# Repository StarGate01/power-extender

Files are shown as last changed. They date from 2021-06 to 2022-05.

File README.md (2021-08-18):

# Power Extender

Hardware and software for a power and IO extension PCB with current monitoring and I2C interface.

This project has been generously supported by [PCBWay](https://www.pcbway.com/). Read more about this project and also my review of the manufacturing on my blog: [Design And Assembly Of An I2C Relay PCB](https://chrz.de/2021/07/16/design-and-assembly-of-an-i2c-relay-pcb/)

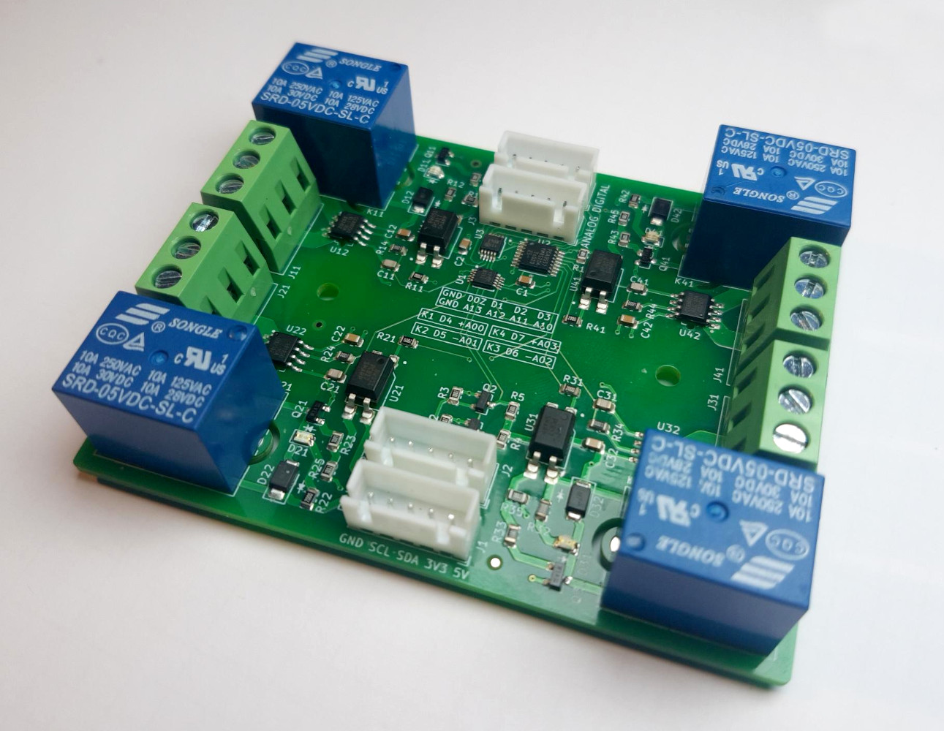
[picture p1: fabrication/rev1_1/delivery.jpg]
PCB


## Usage

Use [KiCad](https://www.kicad.org/) with my [CustomComponents](https://github.com/StarGate01/KiCadLibs) library to view and edit the hardware project, or download the [fabrication files](fabrication) for PCB and/or PCBA manufacturing. I used [KiBOM](https://github.com/SchrodingersGat/kibom) to generate the BOM. You can also download the complete [schematics as PDF](hardware/power-extender_schematics_rev1_1.pdf).

See the [Arduino library documentation](https://github.com/StarGate01/power-extender/tree/master/software/power-extender-arduino/lib/power-extender) for usage with the Arduino framework. The library is also available on [PlatformIO](https://platformio.org/lib/show/12563/power-extender). Use [Visual Studio Code](https://code.visualstudio.com/) and the [PlatformIO](https://platformio.org/) plugin to edit the Arduino library and tests.

See the [Raspberry Pi library documentation](https://github.com/StarGate01/power-extender/tree/master/software/power-extender-raspberrypi) for usage with the Raspberry Pi Python 3 `smbus` framework.

## Features and Specifications

- Power input via `5V` and `3V3` pins
  - Min. `250mA @ 5V` to actuate all four relays simultaneously
  - Less than `30mA @ 5V` standby current
  - `3V3` voltage level is only required for I2C level shifting if the I2C signal level is `3.3V` instead of `5V`
- I2C bus for connection to a I2C master via JST header `RPI`
  - I2C bus passthrough via JST header `PASS`
  - Internal pullup resistors
  - Level-shifting `3.3V - 5V` tolerant bus
- Four `SRD-05VDC-SL-C` three-lead (`NC - COM - NO`) magnetic relays
  - Each has a `CC6902SO-10A` inductive current measuring IC connected across `COM`
  - Galvanically isolated driver circuit using an optocoupler
  - Flyback diode protection
  - Red status LED indicates `COM - NO` actuation
  - `2oz` thick copper traces enable high currents
  - Isolation milling reduces risk of shorting in damp environments
  - Maximum power: `10A, 250VAC, 110VDC`
  - Contact load rating: resistive `7A @ 28VDC`, `10A @ 125VAC`, `7A @ 240VAC`, inductive `3A @ 120VAC`, `3A @ 28VDC`
- One `PCA9557` 8-channel GPIO port (I2C address: `0x18`), logic level `0V | 5V`
  - GPIO channels `0Z` - `3` connected to JST header `DIGITAL`
  - Relays are connected to GPIO channels `4` - `7`
  - Maximum current (except channel `0Z`): `25mA` sink, `20mA` source per channel, max. total: `100mA` sink, `85mA` source
  - Channel `0Z` is high-impedance and open-drain (see datasheet for details)
- Two `ADS1115` 4-channel 16-bit ADC ports, voltage range `0V - 5V`
  - All four pins of ADC 1 connected to current measuring ICs (I2C address: `0x48`)
  - All four pins of ADC 2 connected to JST header `ANALOG` (I2C address: `0x49`)
  - Configurable sample rate and gain amplifier
  - Max. `10mA` continuous input current

For further specifications and ratings, all [datasheets](https://github.com/StarGate01/power-extender/tree/master/datasheets) can be found in this repository.

### Sensor Calibration

Due to the inherent nature of magnetic relays, the inductive current measuring ICs and also the ADCs experience a measurement offset while the relays are energized. It is recommended to measure the actual load at a distance from the board, in order to obtain reference values. These reference values should then be used to compute an offset or function for each channel and amount of relays energized. 

For no load (floating) using an Arduino Uno, the maximum absolute measurement offset was found to be about as follows.

| Amount of relays energized | Offset at energized channel | Offset at disabled channel |
| --- | --- | --- |
| 0 | `0.05A` | `0.05A` |
| 1 | `1A` | `0.7A` |
| 2 | `1.5A` | `1.3A` |
| 3 | `2A` | `1.8A` |
| 4 | `2.4A` | N / A |

Please note that these offsets are dependent on load and environmental factors.

## PCB Details

**17 unique** parts, **60 SMT** parts, **12 THT** parts on a double-sided `90mm x 71mm` PCB with `2oz` copper finish.

Component cost per board: about `$25` (Ignoring shipping, bulk discounts and changes in price over time).

<details>
<summary>BOM</summary>

|Item #|Designator |Quantity|Manufacturer |Manufacturer Part #  |Description / Value |Distributor|Distributor part #|Package / Footprint|Type|Notes|
|---|---|---|---|---|---|---|---|---|----|-----|
|1 |C11, C21, C31, C41 |4 |Any |TBD |CAP CER 100PF MAX. 5% MIN. 10V 0805 SMD |Any |TBD |SMD 0805 |SMD | |
|2 |C1, C2, C12, C22, C32, C42 |6 |Any |TBD |CAP CER 100NF MAX. 5% MIN. 10V 0805 SMD |Any |TBD |SMD 0805 |SMD | |
|3 |D12, D22, D32, D42 |4 |Shikues |1N4007F |DIODE 1N4007 SMAF |LCSC |C110856 |SMAF |SMD | |
|4 |D11, D21, D31, D41 |4 |Everlight Elec |17-21SURC/S530-A3/TR8|LED RED 2V 0805 SMD |LCSC |C72037 |SMD 0805 |SMD | |
|5 |J1, J2, J3, J4 |4 |Any |TBD |CONN JST-XH PITCH-2.50MM VERTICAL MALE 5 PIN|Any |TBD |Through Hole |PTH | |
|6 |J11, J21, J31, J41 |4 |Ningbo Kangnex Elec |WJ128V-5.0-3P |CONN SCREW TERMINAL PITCH-5.0MM 3 PIN 20A |LCSC |C8270 |Through Hole |PTH | |
|7 |K11, K21, K31, K41 |4 |Ningbo Songle Relay |SRD-05VDC-SL-C |RELAY SEALED SENSITIVE 5V 10A |LCSC |C35449 |Through Hole |PTH | |
|8 |Q1, Q2 |2 |Shikues |BSS138 |MOSFET N-CH SOT-23-3 |LCSC |C112239 |SOT-23-3 |SMD | |
|9 |Q11, Q21, Q31, Q41 |4 |Nexperia |PMBT3904,215 |BJT NPN SOT-23-3 |LCSC |C8667 |SOT-23-3 |SMD | |
|10 |R14, R24, R34, R44 |4 |Any |TBD |RES 100 OHM MAX. 1% MIN. 1/8W 0805 SMD |Any |TBD |SMD 0805 |SMD | |
|11 |R11, R12, R21, R22, R31, R32, R41, R42|8 |Any |TBD |RES 200 OHM MAX. 1% MIN. 1/8W 0805 SMD |Any |TBD |SMD 0805 |SMD | |
|12 |R1, R13, R23, R33, R43 |5 |Any |TBD |RES 1K OHM MAX. 1% MIN. 1/8W 0805 SMD |Any |TBD |SMD 0805 |SMD | |
|13 |R2, R3, R4, R5, R15, R25, R35, R45 |8 |Any |TBD |RES 10K OHM MAX. 1% MIN. 1/8W 0805 SMD |Any |TBD |SMD 0805 |SMD | |
|14 |U1, U3 |2 |Texas Instruments |ADS1115IDGSR |IC I2C 4 CH ADC VSSOP-10 |LCSC |C37593 |VSSOP-10 |SMD | |
|15 |U12, U22, U32, U42 |4 |Cross Chip |CC6902SO-10A |IC CURRENT SENSOR 5V 10A SOP-8 |LCSC |C350865 |SOP-8 |SMD | |
|16 |U11, U21, U31, U41 |4 |Sharp Microelectronics|PC817X2CSP9F |IC OPTOCOUPLER SMD-4 |LCSC |C66405 |SMD-4 |SMD | |
|17 |U2 |1 |NXP Semicon |PCA9557PW,118 |IC I2C 8 CH IO EXPANDER TSSOP-16 |LCSC |C141380 |TSSOP-16 |SMD | |

</details>

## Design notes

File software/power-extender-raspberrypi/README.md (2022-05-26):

# namespace `power-extender-raspberrypi::pypowerextender::ADS1115_Registers` 

## Summary

 Members                        | Descriptions                                
--------------------------------|---------------------------------------------
`class `[`power-extender-raspberrypi::pypowerextender::ADS1115_Registers::ADS1115_DR`](#classpower-extender-raspberrypi_1_1pypowerextender_1_1ADS1115__Registers_1_1ADS1115__DR) | 
`class `[`power-extender-raspberrypi::pypowerextender::ADS1115_Registers::ADS1115_PGA`](#classpower-extender-raspberrypi_1_1pypowerextender_1_1ADS1115__Registers_1_1ADS1115__PGA) | 

# class `power-extender-raspberrypi::pypowerextender::ADS1115_Registers::ADS1115_DR` 

```
class power-extender-raspberrypi::pypowerextender::ADS1115_Registers::ADS1115_DR
  : public IntEnum
```  

## Summary

 Members                        | Descriptions                                
--------------------------------|---------------------------------------------

## Members

# class `power-extender-raspberrypi::pypowerextender::ADS1115_Registers::ADS1115_PGA` 

```
class power-extender-raspberrypi::pypowerextender::ADS1115_Registers::ADS1115_PGA
  : public IntEnum
```  

## Summary

 Members                        | Descriptions                                
--------------------------------|---------------------------------------------

## Members

# namespace `power-extender-raspberrypi::pypowerextender::PowerExtender` 

## Summary

 Members                        | Descriptions                                
--------------------------------|---------------------------------------------
`class `[`power-extender-raspberrypi::pypowerextender::PowerExtender::PEPIN_A`](#classpower-extender-raspberrypi_1_1pypowerextender_1_1PowerExtender_1_1PEPIN__A) | Existing analog pins.
`class `[`power-extender-raspberrypi::pypowerextender::PowerExtender::PEPIN_D_IN`](#classpower-extender-raspberrypi_1_1pypowerextender_1_1PowerExtender_1_1PEPIN__D__IN) | Existing GPIO pins for input.
`class `[`power-extender-raspberrypi::pypowerextender::PowerExtender::PEPIN_D_OUT`](#classpower-extender-raspberrypi_1_1pypowerextender_1_1PowerExtender_1_1PEPIN__D__OUT) | Existing GPIO pins for output.
`class `[`power-extender-raspberrypi::pypowerextender::PowerExtender::PEPORT_A`](#classpower-extender-raspberrypi_1_1pypowerextender_1_1PowerExtender_1_1PEPORT__A) | Existing analog ports (separate ADC ICs)
`class `[`power-extender-raspberrypi::pypowerextender::PowerExtender::PINMODE`](#classpower-extender-raspberrypi_1_1pypowerextender_1_1PowerExtender_1_1PINMODE) | Pinmode definitions.
`class `[`power-extender-raspberrypi::pypowerextender::PowerExtender::PINSTATE`](#classpower-extender-raspberrypi_1_1pypowerextender_1_1PowerExtender_1_1PINSTATE) | Pinstate definitions.
`class `[`power-extender-raspberrypi::pypowerextender::PowerExtender::PowerExtender`](#classpower-extender-raspberrypi_1_1pypowerextender_1_1PowerExtender_1_1PowerExtender) | Class to interface the power-extender.

# class `power-extender-raspberrypi::pypowerextender::PowerExtender::PEPIN_A` 

```
class power-extender-raspberrypi::pypowerextender::PowerExtender::PEPIN_A
  : public IntEnum
```  

Existing analog pins.

## Summary

 Members                        | Descriptions                                
--------------------------------|---------------------------------------------

## Members

# class `power-extender-raspberrypi::pypowerextender::PowerExtender::PEPIN_D_IN` 

```
class power-extender-raspberrypi::pypowerextender::PowerExtender::PEPIN_D_IN
  : public IntEnum
```  

Existing GPIO pins for input.

## Summary

 Members                        | Descriptions                                
--------------------------------|---------------------------------------------

## Members

# class `power-extender-raspberrypi::pypowerextender::PowerExtender::PEPIN_D_OUT` 

```
class power-extender-raspberrypi::pypowerextender::PowerExtender::PEPIN_D_OUT
  : public IntEnum
```  

Existing GPIO pins for output.

## Summary

 Members                        | Descriptions                                
--------------------------------|---------------------------------------------

## Members

# class `power-extender-raspberrypi::pypowerextender::PowerExtender::PEPORT_A` 

```
class power-extender-raspberrypi::pypowerextender::PowerExtender::PEPORT_A
  : public IntEnum
```  

Existing analog ports (separate ADC ICs)

## Summary

 Members                        | Descriptions                                
--------------------------------|---------------------------------------------

## Members

# class `power-extender-raspberrypi::pypowerextender::PowerExtender::PINMODE` 

```
class power-extender-raspberrypi::pypowerextender::PowerExtender::PINMODE
  : public IntEnum
```  

Pinmode definitions.

## Summary

 Members                        | Descriptions                                
--------------------------------|---------------------------------------------

## Members

# class `power-extender-raspberrypi::pypowerextender::PowerExtender::PINSTATE` 

```
class power-extender-raspberrypi::pypowerextender::PowerExtender::PINSTATE
  : public IntEnum
```  

Pinstate definitions.

## Summary

 Members                        | Descriptions                                
--------------------------------|---------------------------------------------

## Members

# class `power-extender-raspberrypi::pypowerextender::PowerExtender::PowerExtender` 

Class to interface the power-extender.

## Summary

 Members                        | Descriptions                                
--------------------------------|---------------------------------------------
`public def `[`__init__`](#classpower-extender-raspberrypi_1_1pypowerextender_1_1PowerExtender_1_1PowerExtender_1ad7f74c05e4f81fff44294663b4eea909)`(self)` | Construct a new Power Extender object.
`public def `[`begin`](#classpower-extender-raspberrypi_1_1pypowerextender_1_1PowerExtender_1_1PowerExtender_1a77635c29b3e975602f4de08570c5ab66)`(self,int bus)` | Begin I2C communication.
`public def `[`setPinMode`](#classpower-extender-raspberrypi_1_1pypowerextender_1_1PowerExtender_1_1PowerExtender_1a28935d2fa3f4e8e0b9178cc93a20c7da)`(self,`[`PEPIN_D_IN`](#classpower-extender-raspberrypi_1_1pypowerextender_1_1PowerExtender_1_1PEPIN__D__IN)` pin,`[`PINMODE`](#classpower-extender-raspberrypi_1_1pypowerextender_1_1PowerExtender_1_1PINMODE)` mode)` | Configure the IO direction of a GPIO pin.
`public def `[`digitalWrite`](#classpower-extender-raspberrypi_1_1pypowerextender_1_1PowerExtender_1_1PowerExtender_1ab420235d8b39cf3ac0c35061d8b65c75)`(self,`[`PEPIN_D_OUT`](#classpower-extender-raspberrypi_1_1pypowerextender_1_1PowerExtender_1_1PEPIN__D__OUT)` pin,`[`PINSTATE`](#classpower-extender-raspberrypi_1_1pypowerextender_1_1PowerExtender_1_1PINSTATE)` val)` | Change the state of a GPIO output pin.
`public `[`PINSTATE`](#classpower-extender-raspberrypi_1_1pypowerextender_1_1PowerExtender_1_1PINSTATE)` `[`digitalRead`](#classpower-extender-raspberrypi_1_1pypowerextender_1_1PowerExtender_1_1PowerExtender_1a331cdf53cb1d2a52321073b417b7b7f9)`(self,`[`PEPIN_D_IN`](#classpower-extender-raspberrypi_1_1pypowerextender_1_1PowerExtender_1_1PEPIN__D__IN)` pin)` | Reads the state of a digital input pin.
`public def `[`setAnalogDataRate`](#classpower-extender-raspberrypi_1_1pypowerextender_1_1PowerExtender_1_1PowerExtender_1afaa7bde6af7c3c3387ab650a0db28946)`(self,`[`PEPORT_A`](#classpower-extender-raspberrypi_1_1pypowerextender_1_1PowerExtender_1_1PEPORT__A)` port,`[`ADS1115_Registers.ADS1115_DR`](#classpower-extender-raspberrypi_1_1pypowerextender_1_1ADS1115__Registers_1_1ADS1115__DR)` data_rate)` | Set the data rate for a whole ADC.
`public def `[`setAnalogGain`](#classpower-extender-raspberrypi_1_1pypowerextender_1_1PowerExtender_1_1PowerExtender_1aebfcff18640a7b7a253666d899e245f7)`(self,`[`PEPORT_A`](#classpower-extender-raspberrypi_1_1pypowerextender_1_1PowerExtender_1_1PEPORT__A)` port,`[`ADS1115_Registers.ADS1115_PGA`](#classpower-extender-raspberrypi_1_1pypowerextender_1_1ADS1115__Registers_1_1ADS1115__PGA)` gain)` | Set the gain for a whole ADC.
`public float `[`analogReadAsVoltage`](#classpower-extender-raspberrypi_1_1pypowerextender_1_1PowerExtender_1_1PowerExtender_1a7926271bf71a0f24b47373fe16b307e5)`(self,`[`PEPIN_A`](#classpower-extender-raspberrypi_1_1pypowerextender_1_1PowerExtender_1_1PEPIN__A)` pin)` | Reads from an ADC, convert to input voltage.
`public float `[`analogReadAsCurrent`](#classpower-extender-raspberrypi_1_1pypowerextender_1_1PowerExtender_1_1PowerExtender_1a526f8b8f57397ae1fa46358c1610d534)`(self,`[`PEPIN_A`](#classpower-extender-raspberrypi_1_1pypowerextender_1_1PowerExtender_1_1PEPIN__A)` pin)` | Reads from an ADC, convert to output from current sensor.

## Members

#### `public def `[`__init__`](#classpower-extender-raspberrypi_1_1pypowerextender_1_1PowerExtender_1_1PowerExtender_1ad7f74c05e4f81fff44294663b4eea909)`(self)` 

Construct a new Power Extender object.

#### `public def `[`begin`](#classpower-extender-raspberrypi_1_1pypowerextender_1_1PowerExtender_1_1PowerExtender_1a77635c29b3e975602f4de08570c5ab66)`(self,int bus)` 

Begin I2C communication.

#### `public def `[`setPinMode`](#classpower-extender-raspberrypi_1_1pypowerextender_1_1PowerExtender_1_1PowerExtender_1a28935d2fa3f4e8e0b9178cc93a20c7da)`(self,`[`PEPIN_D_IN`](#classpower-extender-raspberrypi_1_1pypowerextender_1_1PowerExtender_1_1PEPIN__D__IN)` pin,`[`PINMODE`](#classpower-extender-raspberrypi_1_1pypowerextender_1_1PowerExtender_1_1PINMODE)` mode)` 

Configure the IO direction of a GPIO pin.

#### Parameters
* `pin` Which pin to configure 

* `mode` INPUT or OUTPUT

#### `public def `[`digitalWrite`](#classpower-extender-raspberrypi_1_1pypowerextender_1_1PowerExtender_1_1PowerExtender_1ab420235d8b39cf3ac0c35061d8b65c75)`(self,`[`PEPIN_D_OUT`](#classpower-extender-raspberrypi_1_1pypowerextender_1_1PowerExtender_1_1PEPIN__D__OUT)` pin,`[`PINSTATE`](#classpower-extender-raspberrypi_1_1pypowerextender_1_1PowerExtender_1_1PINSTATE)` val)` 

Change the state of a GPIO output pin.

#### Parameters
* `pin` Which pin to change 

* `val` HIGH or LOW

#### `public `[`PINSTATE`](#classpower-extender-raspberrypi_1_1pypowerextender_1_1PowerExtender_1_1PINSTATE)` `[`digitalRead`](#classpower-extender-raspberrypi_1_1pypowerextender_1_1PowerExtender_1_1PowerExtender_1a331cdf53cb1d2a52321073b417b7b7f9)`(self,`[`PEPIN_D_IN`](#classpower-extender-raspberrypi_1_1pypowerextender_1_1PowerExtender_1_1PEPIN__D__IN)` pin)` 

Reads the state of a digital input pin.

#### Parameters
* `pin` Which pin to read 

#### Returns
HIGH or LOW

#### `public def `[`setAnalogDataRate`](#classpower-extender-raspberrypi_1_1pypowerextender_1_1PowerExtender_1_1PowerExtender_1afaa7bde6af7c3c3387ab650a0db28946)`(self,`[`PEPORT_A`](#classpower-extender-raspberrypi_1_1pypowerextender_1_1PowerExtender_1_1PEPORT__A)` port,`[`ADS1115_Registers.ADS1115_DR`](#classpower-extender-raspberrypi_1_1pypowerextender_1_1ADS1115__Registers_1_1ADS1115__DR)` data_rate)` 

Set the data rate for a whole ADC.

#### Parameters
* `port` Which ADC port to configure 

* `data_rate` The new data rate

#### `public def `[`setAnalogGain`](#classpower-extender-raspberrypi_1_1pypowerextender_1_1PowerExtender_1_1PowerExtender_1aebfcff18640a7b7a253666d899e245f7)`(self,`[`PEPORT_A`](#classpower-extender-raspberrypi_1_1pypowerextender_1_1PowerExtender_1_1PEPORT__A)` port,`[`ADS1115_Registers.ADS1115_PGA`](#classpower-extender-raspberrypi_1_1pypowerextender_1_1ADS1115__Registers_1_1ADS1115__PGA)` gain)` 

Set the gain for a whole ADC.

#### Parameters
* `port` Which ADC to configure 

* `gain` The new gain

#### `public float `[`analogReadAsVoltage`](#classpower-extender-raspberrypi_1_1pypowerextender_1_1PowerExtender_1_1PowerExtender_1a7926271bf71a0f24b47373fe16b307e5)`(self,`[`PEPIN_A`](#classpower-extender-raspberrypi_1_1pypowerextender_1_1PowerExtender_1_1PEPIN__A)` pin)` 

Reads from an ADC, convert to input voltage.

#### Parameters
* `pin` Which pin to read 

#### Returns
The resulting value in volt

#### `public float `[`analogReadAsCurrent`](#classpower-extender-raspberrypi_1_1pypowerextender_1_1PowerExtender_1_1PowerExtender_1a526f8b8f57397ae1fa46358c1610d534)`(self,`[`PEPIN_A`](#classpower-extender-raspberrypi_1_1pypowerextender_1_1PowerExtender_1_1PEPIN__A)` pin)` 

Reads from an ADC, convert to output from current sensor.

#### Parameters
* `pin` Which pin to read 

#### Returns
The resulting value in ampere

Generated by [Moxygen](https://sourcey.com/moxygen)

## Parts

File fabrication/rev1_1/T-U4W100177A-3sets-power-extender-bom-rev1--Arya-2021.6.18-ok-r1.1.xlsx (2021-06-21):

Item # | Designator | Quantity | Manufacturer | Manufacturer Part # | Description / Value | Distributor | Distributor part # | Package / Footprint | Type | Notes | Unit price 3sets |  | NOTE
1 | C11, C21, C31, C41 | 4 | Any | TBD | CAP CER 100PF MAX. 5% MIN. 10V 0805 SMD | Any | TBD | SMD 0805 | SMD | OK | $0.055 | $0.660 | CL21C101JBANNNC(CAP CER 100PF 50V C0G/NP0 0805),ok？
2 | C1, C2, C12, C22, C32, C42 | 6 | Any | TBD | CAP CER 100NF MAX. 5% MIN. 10V 0805 SMD | Any | TBD | SMD 0805 | SMD | OK | $0.105 | $1.890 | CC0805JRX7R9BB104(CAP CER 0.1UF 50V X7R 0805),ok？
3 | D12, D22, D32, D42 | 4 | Shikues | 1N4007F | DIODE 1N4007 SMAF | LCSC | C110856 | SMAF | SMD |  | $0.055 | $0.660
4 | D11, D21, D31, D41 | 4 | Everlight Elec | 17-21SURC/S530-A3/TR8 | LED RED 2V 0805 SMD | LCSC | C72037 | SMD 0805 | SMD |  | $0.105 | $1.260
5 | J1, J2, J3, J4 | 4 | Any | TBD | CONN JST-XH PITCH-2.50MM VERTICAL MALE 5 PIN | Any | TBD | Through Hole | PTH | OK, Must use PCB Rev 1.1 | $0.210 | $2.520 | XH2.54mm 5p male socket, 180 degree in vertical,ok?
6 | J11, J21, J31, J41 | 4 | Ningbo Kangnex Elec | WJ128V-5.0-3P | CONN SCREW TERMINAL PITCH-5.0MM 3 PIN 20A | LCSC | C8270 | Through Hole | PTH |  | $0.195 | $2.340
7 | K11, K21, K31, K41 | 4 | Ningbo Songle Relay | SRD-05VDC-SL-C | RELAY SEALED SENSITIVE 5V 10A | LCSC | C35449 | Through Hole | PTH |  | $0.398 | $4.776
8 | Q1, Q2 | 2 | Shikues | BSS138 | MOSFET N-CH SOT-23-3 | LCSC | C112239 | SOT-23-3 | SMD |  | $0.125 | $0.750
9 | Q11, Q21, Q31, Q41 | 4 | Nexperia | PMBT3904,215 | BJT NPN SOT-23-3 | LCSC | C8667 | SOT-23-3 | SMD |  | $0.325 | $3.900
10 | R14, R24, R34, R44 | 4 | Any | TBD | RES 100 OHM MAX. 1% MIN. 1/8W 0805 SMD | Any | TBD | SMD 0805 | SMD | OK | $0.055 | $0.660 | RC0805FR-07100RL(RES SMD 100 OHM 1% 1/8W 0805),ok？
11 | R11, R12, R21, R22, R31, R32, R41, R42 | 8 | Any | TBD | RES 200 OHM MAX. 1% MIN. 1/8W 0805 SMD | Any | TBD | SMD 0805 | SMD | OK | $0.055 | $1.320 | RC0805FR-07200RL(RES SMD 200 OHM 1% 1/8W 0805),ok？
12 | R1, R13, R23, R33, R43 | 5 | Any | TBD | RES 1K OHM MAX. 1% MIN. 1/8W 0805 SMD | Any | TBD | SMD 0805 | SMD | OK | $0.055 | $0.825 | RC0805FR-071KL(RES SMD 1K OHM 1% 1/8W 0805),ok？
13 | R2, R3, R4, R5, R15, R25, R35, R45 | 8 | Any | TBD | RES 10K OHM MAX. 1% MIN. 1/8W 0805 SMD | Any | TBD | SMD 0805 | SMD | OK | $0.055 | $1.320 | RC0805FR-0710KL(RES SMD 10K OHM 1% 1/8W 0805),ok？
14 | U1, U3 | 2 | Texas Instruments | ADS1115IDGSR | IC I2C 4 CH ADC VSSOP-10 | LCSC | C37593 | VSSOP-10 | SMD |  | $5.398 | $32.388
15 | U12, U22, U32, U42 | 4 | Cross Chip | CC6902SO-10A | IC CURRENT SENSOR 5V 10A SOP-8 | LCSC | C350865 | SOP-8 | SMD |  | $1.050 | $12.600
16 | U11, U21, U31, U41 | 4 | Sharp Microelectronics | PC817X2CSP9F | IC OPTOCOUPLER SMD-4 | LCSC | C66405 | SMD-4 | SMD |  | $0.150 | $1.800
17 | U2 | 1 | NXP Semicon | PCA9557PW,118 | IC I2C 8 CH IO EXPANDER TSSOP-16 | LCSC | C141380 | TSSOP-16 | SMD |  | $0.825 | $2.475
 |  |  |  |  |  |  |  |  |  |  | 7-10work days
 |  |  |  |  |  |  |  |  |  |  | Per Manufacturer Part #
 |  |  |  |  |  |  |  |  |  | OK |  | 72.144

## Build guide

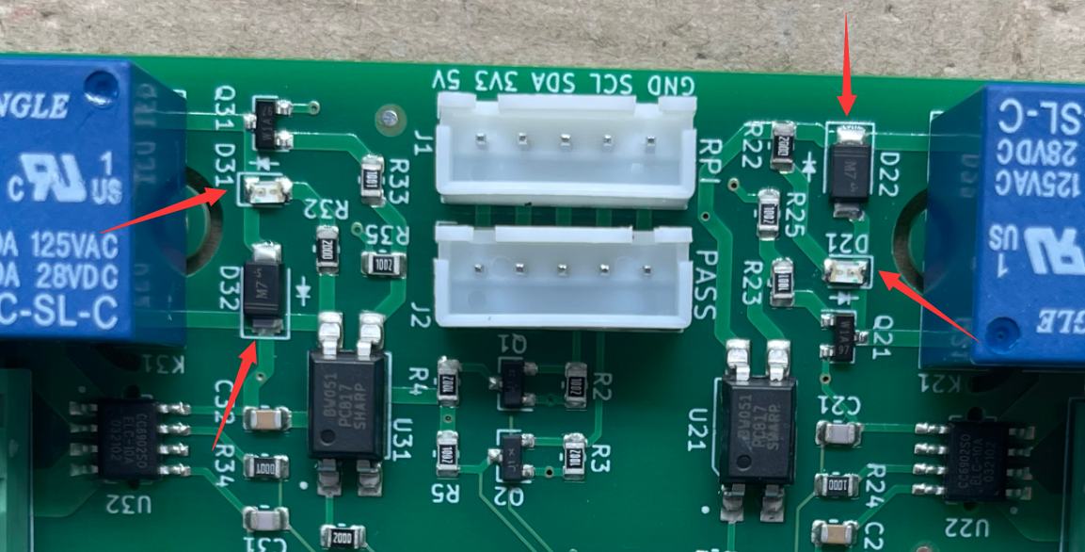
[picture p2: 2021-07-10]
fabrication/rev1_1/sma_review/The arrow indicates cathode-02.png

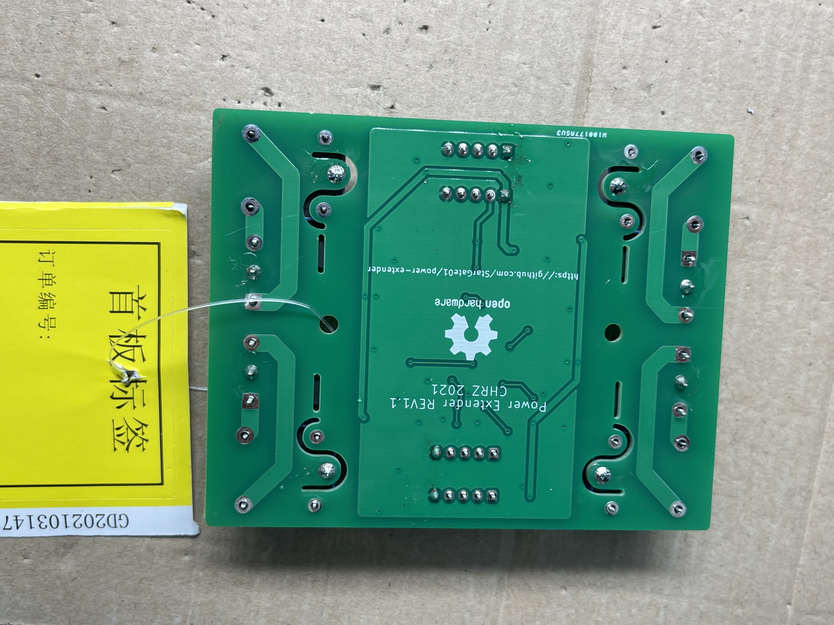
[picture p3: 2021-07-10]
fabrication/rev1_1/sma_review/T-U4W100177A-02.JPG

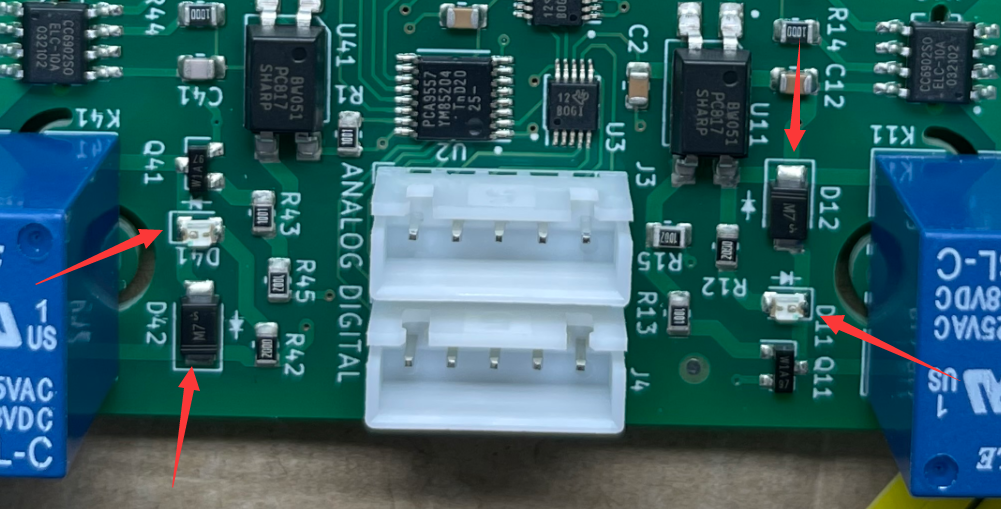
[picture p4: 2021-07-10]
fabrication/rev1_1/sma_review/The arrow indicates cathode-01.png

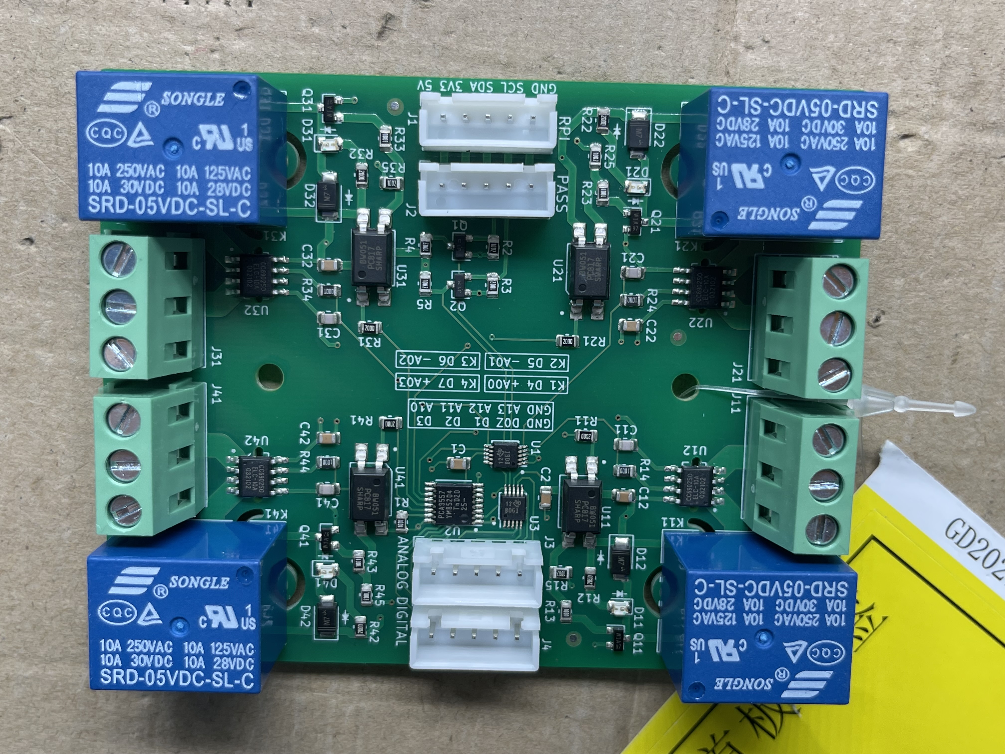
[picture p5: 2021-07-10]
fabrication/rev1_1/sma_review/T-U4W100177A-01.JPG

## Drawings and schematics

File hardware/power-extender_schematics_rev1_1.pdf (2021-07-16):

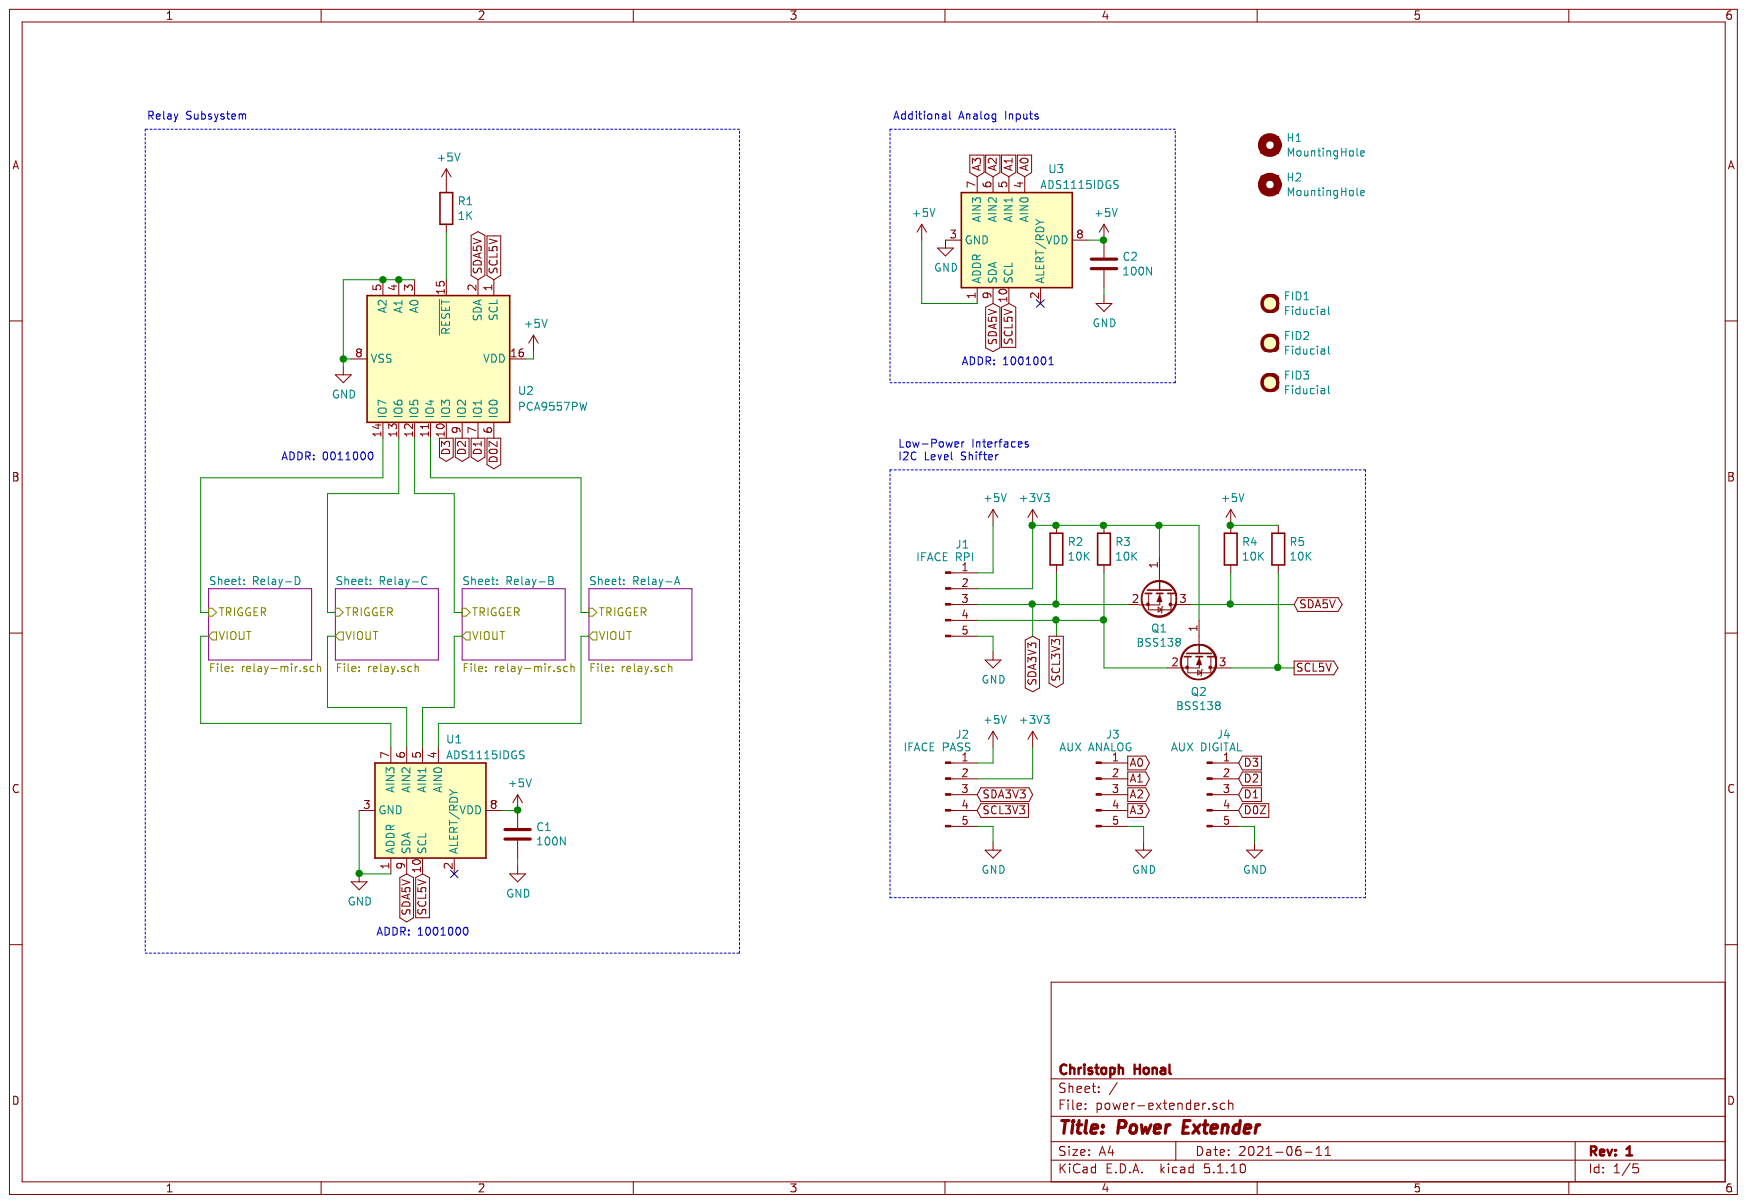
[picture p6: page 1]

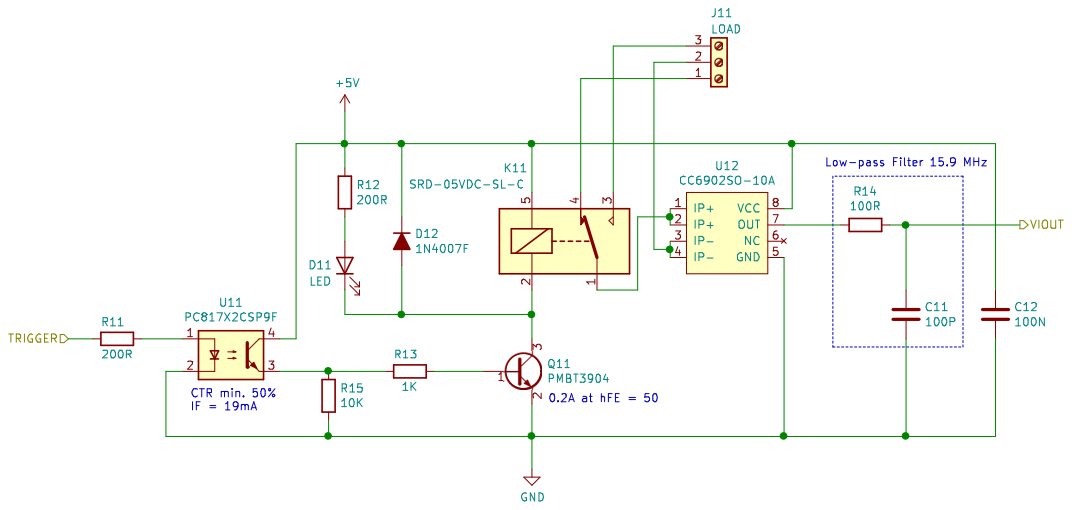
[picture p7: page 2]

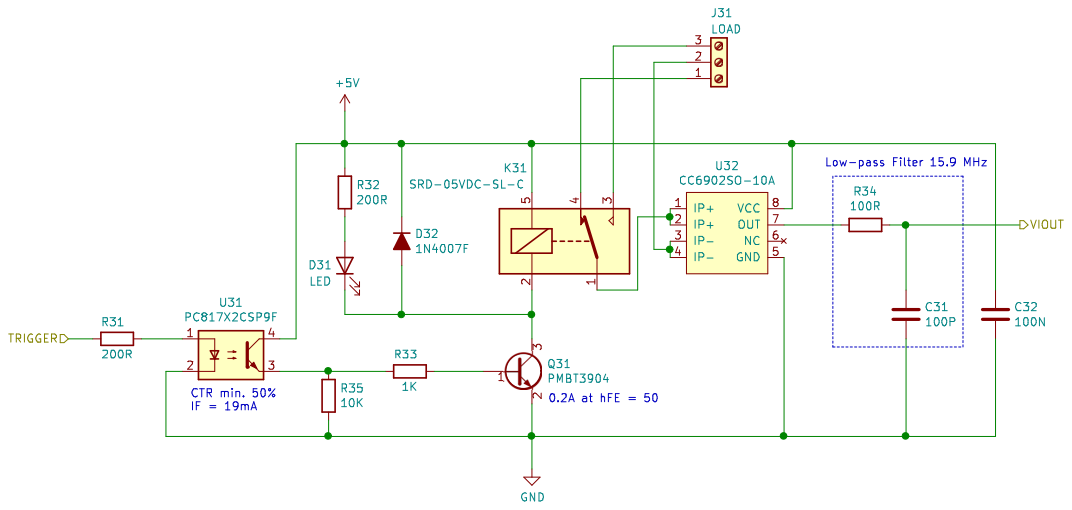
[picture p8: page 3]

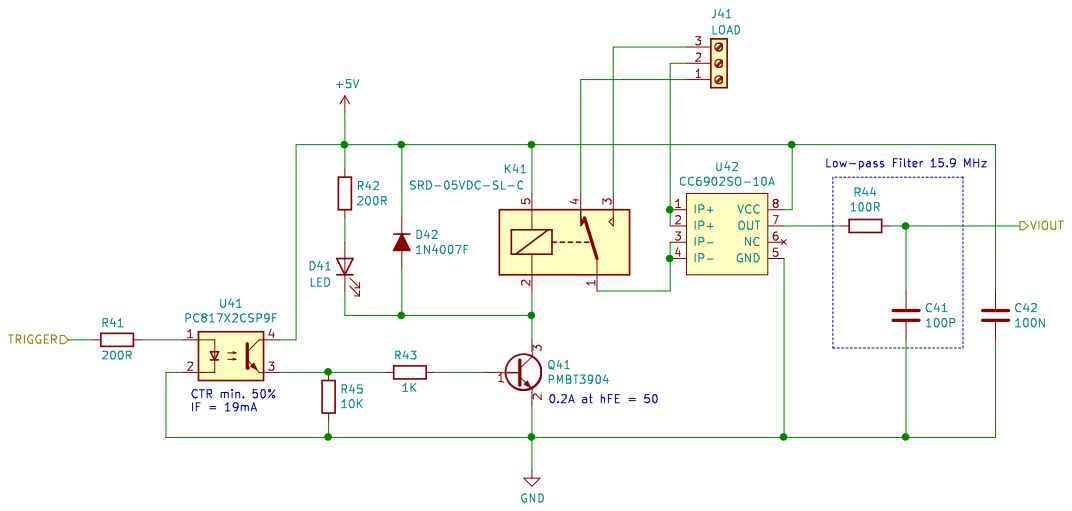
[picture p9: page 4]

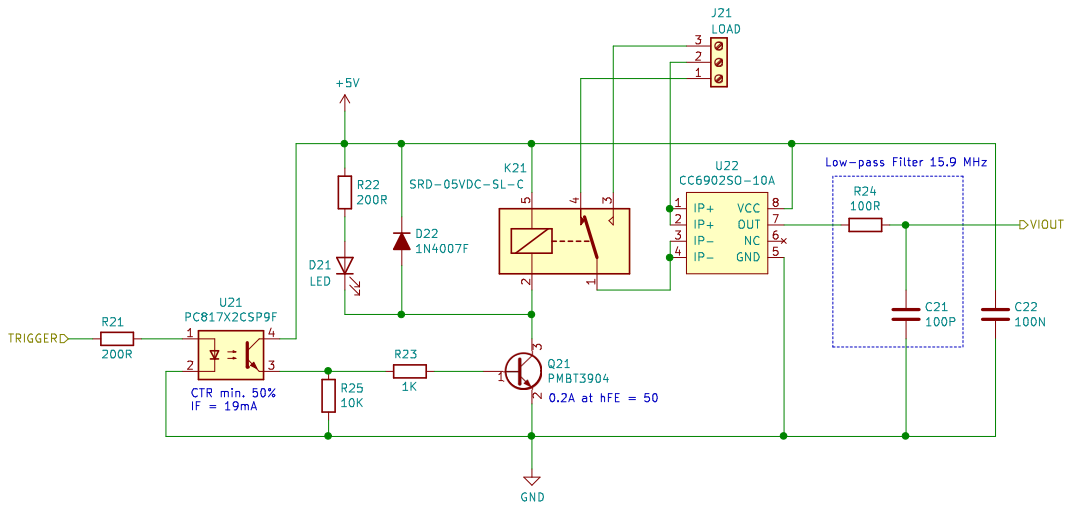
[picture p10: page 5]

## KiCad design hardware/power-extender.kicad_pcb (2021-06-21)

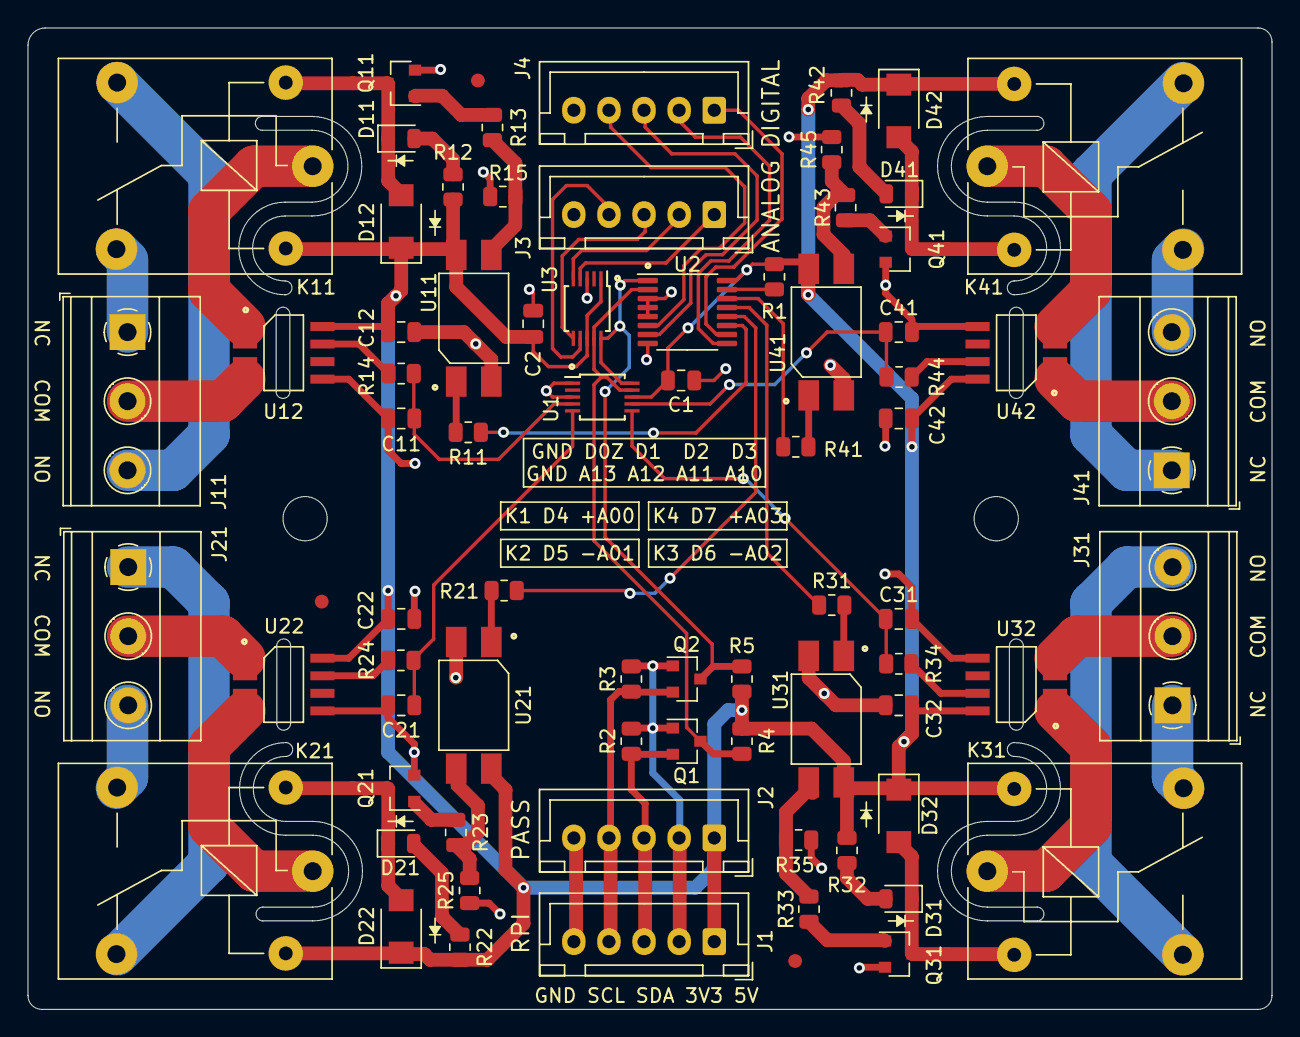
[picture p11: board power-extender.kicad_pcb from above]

Board: 2 copper layers, 90.0 x 71.0 mm, 77 parts (0 on the bottom side), 64 nets.

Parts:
C1, C2, C12, C22, C32, C42: 100N; C_0805_2012Metric
C11, C21, C31, C41: 100P; C_0805_2012Metric
D11, D21, D31, D41: LED; LED_0805_2012Metric
D12, D22, D32, D42: 1N4007F; D_SMAF
FID1, FID2, FID3: Fiducial; Fiducial_1mm_Mask2mm
H1, H2: MountingHole; MountingHole_3.2mm_M3
J1: IFACE RPI; JST_XH_B5B-XH-A_1x05_P2.54mm_Vertical
J2: IFACE PASS; JST_XH_B5B-XH-A_1x05_P2.54mm_Vertical
J3: AUX ANALOG; JST_XH_B5B-XH-A_1x05_P2.54mm_Vertical
J4: AUX DIGITAL; JST_XH_B5B-XH-A_1x05_P2.54mm_Vertical
J11, J21, J31, J41: LOAD; TerminalBlock_Phoenix_MKDS-1,5-3_1x03_P5.00mm_Horizontal
K11, K21, K31, K41: SRD-05VDC-SL-C; Relay_SPDT_SANYOU_SRD_Series_Form_C
Q1, Q2: BSS138; SOT-23
Q11, Q21, Q31, Q41: PMBT3904; SOT-23
R1, R13, R23, R33, R43: 1K; R_0805_2012Metric
R2, R3, R4, R5, R15, R25, R35, R45: 10K; R_0805_2012Metric
R11, R12, R21, R22, R31, R32, R41, R42: 200R; R_0805_2012Metric
R14, R24, R34, R44: 100R; R_0805_2012Metric
U1, U3: ADS1115IDGS; TSSOP-10_3x3mm_P0.5mm
U2: PCA9557PW; TSSOP-16_4.4x5mm_P0.65mm
U11, U21, U31, U41: PC817X2CSP9F
U12, U22, U32, U42: CC6902SO-10A; CC690XSO-XA

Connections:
+3V3: J1.2, J2.2, Q1.1, Q2.1, R2.1, R3.1
+5V: C1.1, C2.1, C12.1, C22.1, C32.1, C42.1, D12.1, D22.1, D32.1, D42.1, J1.1, J2.1, K11.5, K21.5, K31.5, K41.5, R1.1, R4.1, R5.1, R12.1, R22.1, R32.1, R42.1, U1.8, U2.16, U3.1, U3.8, U11.4, U12.8, U21.4, U22.8, U31.4, U32.8, U41.4, U42.8
/Relay-A/TRIGGER: R11.1, U2.11
/Relay-A/VIOUT: C11.1, R14.1, U1.4
/Relay-B/TRIGGER: R21.1, U2.12
/Relay-B/VIOUT: C21.1, R24.1, U1.5
/Relay-C/TRIGGER: R31.1, U2.13
/Relay-C/VIOUT: C31.1, R34.1, U1.6
/Relay-D/TRIGGER: R41.1, U2.14
/Relay-D/VIOUT: C41.1, R44.1, U1.7
A0: J3.1, U3.4
A1: J3.2, U3.5
A2: J3.3, U3.6
A3: J3.4, U3.7
D0Z: J4.4, U2.6
D1: J4.3, U2.7
D2: J4.2, U2.9
D3: J4.1, U2.10
GND: C1.2, C2.2, C11.2, C12.2, C21.2, C22.2, C31.2, C32.2, C41.2, C42.2, J1.5, J2.5, J3.5, J4.5, Q11.2, Q21.2, Q31.2, Q41.2, R15.2, R25.2, R35.2, R45.2, U1.1, U1.3, U2.3, U2.4, U2.5, U2.8, U3.3, U11.2, U12.5, U21.2, U22.5, U31.2, U32.5, U41.2, U42.5
unnamed: D11.1, D12.2, K11.2, Q11.3
unnamed: D11.2, R12.2
unnamed: D21.1, D22.2, K21.2, Q21.3
unnamed: D21.2, R22.2
unnamed: D31.1, D32.2, K31.2, Q31.3
unnamed: D31.2, R32.2
unnamed: D41.1, D42.2, K41.2, Q41.3
unnamed: D41.2, R42.2
unnamed: J11.1, K11.4
unnamed: J11.2, U12.3, U12.4
unnamed: J11.3, K11.3
unnamed: J21.1, K21.4
unnamed: J21.2, U22.1, U22.2
unnamed: J21.3, K21.3
unnamed: J31.1, K31.4
unnamed: J31.2, U32.3, U32.4
unnamed: J31.3, K31.3
unnamed: J41.1, K41.4
unnamed: J41.2, U42.1, U42.2
unnamed: J41.3, K41.3
unnamed: K11.1, U12.1, U12.2
unnamed: K21.1, U22.3, U22.4
unnamed: K31.1, U32.1, U32.2
unnamed: K41.1, U42.3, U42.4
unnamed: Q11.1, R13.2
unnamed: Q21.1, R23.2
unnamed: Q31.1, R33.2
unnamed: Q41.1, R43.2
unnamed: R1.2, U2.15
unnamed: R11.2, U11.1
unnamed: R13.1, R15.1, U11.3
unnamed: R14.2, U12.7
unnamed: R21.2, U21.1
unnamed: R23.1, R25.1, U21.3
unnamed: R24.2, U22.7
unnamed: R31.2, U31.1
unnamed: R33.1, R35.1, U31.3
unnamed: R34.2, U32.7
unnamed: R41.2, U41.1
unnamed: R43.1, R45.1, U41.3
unnamed: R44.2, U42.7
SCL3V3: J1.4, J2.4, Q2.2, R3.2
SCL5V: Q2.3, R5.2, U1.10, U2.1, U3.10
SDA3V3: J1.3, J2.3, Q1.2, R2.2
SDA5V: Q1.3, R4.2, U1.9, U2.2, U3.9

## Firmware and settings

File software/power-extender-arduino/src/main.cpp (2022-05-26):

/**
 * @file main.cpp
 * @author Christoph Honal
 * @brief Implements some test code for the power-extender library
 * @version 0.0.1
 * @date 2021-07-15
 */

#include <Arduino.h>

#include "PowerExtender.h"


PowerExtender power_extender;


void setup()
{
    Serial.begin(9600);
    Serial.println("Hello!");

    power_extender.begin();

    power_extender.setPinMode(PEPIN_DIN_1, INPUT);
    power_extender.setPinMode(PEPIN_DIN_2, INPUT);
    power_extender.setPinMode(PEPIN_DIN_3, OUTPUT);
}

double k1 = 0, k2 = 0, k3 = 0, k4 = 0;
uint8_t d1, d2;
int cnt = 0;
bool state = false;

void loop()
{
    k1 = power_extender.analogReadAsCurrent(PEPIN_AK1);
    k2 = power_extender.analogReadAsCurrent(PEPIN_AK2);
    k3 = power_extender.analogReadAsCurrent(PEPIN_AK3);
    k4 = power_extender.analogReadAsVoltage(PEPIN_A10);

    Serial.print(k1);
    Serial.print(";");
    Serial.print(k2);
    Serial.print(";");
    Serial.print(k3);
    Serial.print(";");
    Serial.print(k4);
    Serial.print(";");
    // Serial.print("\n");

    d1 = power_extender.digitalRead(PEPIN_DIN_1);
    d2 = power_extender.digitalRead(PEPIN_DIN_2);

    Serial.print(d1);
    Serial.print(";");
    Serial.print(d2);
    Serial.print("\n");

    if(cnt % 20 == 0)
    {
        state = !state;
        power_extender.digitalWrite(PEPIN_DOUT_K1, state? HIGH:LOW);
        power_extender.digitalWrite(PEPIN_DOUT_K2, state? HIGH:LOW);
        power_extender.digitalWrite(PEPIN_DOUT_K3, state? HIGH:LOW);
        power_extender.digitalWrite(PEPIN_DOUT_K4, state? HIGH:LOW);

        power_extender.digitalWrite(PEPIN_DOUT_3, state? LOW:HIGH);
    }

    cnt++;
    delay(100);
}

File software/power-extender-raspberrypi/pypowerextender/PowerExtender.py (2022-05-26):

## @package pypowerextender
# @file PowerExtender.py
# @author Christoph Honal
# @brief Defines function to interface the power-extender board
# @version 0.0.1
# @date 2021-07-20

from enum import IntEnum
import smbus
import time

from . import ADS1115_Registers
from . import PCA9557_Registers


PERIPHERAL_GPIO_ADDRESS = 0x18 ## I2C address of the GPIO IC
PERIPHERAL_ADC_RELAY_ADDRESS = 0x48 ## I2C address of the ADC connected to the relays
PERIPHERAL_ADC_AUX_ADDRESS = 0x49 ## I2C address of the ADC connected to the external pins 

## Existing GPIO pins for output
class PEPIN_D_OUT(IntEnum):
    PEPIN_DOUT_0Z = 0
    PEPIN_DOUT_1 = 1
    PEPIN_DOUT_2 = 2
    PEPIN_DOUT_3 = 3
    PEPIN_DOUT_K1 = 4
    PEPIN_DOUT_K2 = 5
    PEPIN_DOUT_K3 = 6
    PEPIN_DOUT_K4 = 7

## Existing GPIO pins for input
class PEPIN_D_IN(IntEnum):
    PEPIN_DIN_0Z = 0
    PEPIN_DIN_1 = 1
    PEPIN_DIN_2 = 2
    PEPIN_DIN_3 = 3

## Existing analog ports (separate ADC ICs)
class PEPORT_A(IntEnum):
    PEPORT_AK = 0
    PEPORT_A1 = 1

## Existing analog pins
class PEPIN_A(IntEnum):
    PEPIN_AK1 = 0
    PEPIN_AK2 = 1
    PEPIN_AK3 = 2
    PEPIN_AK4 = 3
    PEPIN_A10 = 10
    PEPIN_A11 = 11
    PEPIN_A12 = 12
    PEPIN_A13 = 13

## Pinmode definitions
class PINMODE(IntEnum):
    INPUT = 0
    OUTPUT = 1

## Pinstate definitions
class PINSTATE(IntEnum):
    LOW = 0
    HIGH = 1


## Class to interface the power-extender
class PowerExtender:

    ## Construct a new Power Extender object
    def __init__(self):
        self._adc_address = [ PERIPHERAL_ADC_RELAY_ADDRESS, PERIPHERAL_ADC_AUX_ADDRESS ] ## ADC address map
        self._gpio_out = 0x00 ## GPIO register chache
        self._gpio_mode = 0x00 ## GPIO register chache
        self._data_rate = [ ADS1115_Registers.ADS1115_DR.DR_64, ADS1115_Registers.ADS1115_DR.DR_64 ] ## Configured data rates
        self._gain = [ ADS1115_Registers.ADS1115_PGA.PGA_6_144, ADS1115_Registers.ADS1115_PGA.PGA_6_144 ] ## Configured gains


    ## Begin I2C communication
    def begin(self, bus: int = 1):
        self._bus = smbus.SMBus(bus)

        # Init GPIO
        self._writeRegister(PERIPHERAL_GPIO_ADDRESS, PCA9557_Registers.PCA9557_REG_CONTROL_CONFIGURATION, 0x00) # Set all GPIO to output
        self._writeRegister(PERIPHERAL_GPIO_ADDRESS, PCA9557_Registers.PCA9557_REG_CONTROL_POLARITY_INVERSION, 0x00) # No polarity inversion
        self._writeRegister(PERIPHERAL_GPIO_ADDRESS, PCA9557_Registers.PCA9557_REG_CONTROL_OUTPUT_PORT, 0x00) # Turn off all GPIOs

        # Init ADCs
        self._reconfigureADC(PEPORT_A.PEPORT_AK)
        self._reconfigureADC(PEPORT_A.PEPORT_A1)


    ## Configure the IO direction of a GPIO pin
    #
    # @param pin Which pin to configure
    # @param mode INPUT or OUTPUT
    def setPinMode(self, pin: PEPIN_D_IN, mode: PINMODE):
        if(pin > PEPIN_D_IN.PEPIN_DIN_3 or pin < PEPIN_D_IN.PEPIN_DIN_0Z): return

        # Clear or set bit in cached pinmap
        if(mode == PINMODE.OUTPUT): self._gpio_mode &= ~(0x01 << pin)
        elif(mode == PINMODE.INPUT): self._gpio_mode |= 0x01 << pin

        # Upload pinmap
        self._writeRegister(PERIPHERAL_GPIO_ADDRESS, PCA9557_Registers.PCA9557_REG_CONTROL_CONFIGURATION, self._gpio_mode)


    ## Change the state of a GPIO output pin
    # 
    # @param pin Which pin to change
    # @param val HIGH or LOW
    def digitalWrite(self, pin: PEPIN_D_OUT, val: PINSTATE):
        if(pin > PEPIN_D_OUT.PEPIN_DOUT_K4 or pin < PEPIN_D_OUT.PEPIN_DOUT_0Z): return

        # Clear or set bit in cached output map
        if(val == PINSTATE.LOW): self._gpio_out &= ~(0x01 << pin)
        elif(val == PINSTATE.HIGH): self._gpio_out |= (0x01 << pin)

        # Upload output map
        self._writeRegister(PERIPHERAL_GPIO_ADDRESS, PCA9557_Registers.PCA9557_REG_CONTROL_OUTPUT_PORT, self._gpio_out)


    ## Reads the state of a digital input pin
    # 
    # @param pin Which pin to read
    # @return HIGH or LOW
    def digitalRead(self, pin: PEPIN_D_IN) -> PINSTATE:
        if(pin > PEPIN_D_IN.PEPIN_DIN_3 or pin < PEPIN_D_IN.PEPIN_DIN_0Z): return 0

        # Read from input map
        state = self._readRegister(PERIPHERAL_GPIO_ADDRESS, PCA9557_Registers.PCA9557_REG_CONTROL_INPUT_PORT)

        # Check specific pin
        return PINSTATE.HIGH if (state & (0x01 << pin)) else PINSTATE.LOW


    ## Set the data rate for a whole ADC
    # 
    # @param port Which ADC port to configure
    # @param data_rate The new data rate
    def setAnalogDataRate(self, port: PEPORT_A, data_rate: ADS1115_Registers.ADS1115_DR):
        if(port > PEPORT_A.PEPORT_A1 or port < PEPORT_A.PEPORT_AK): return

        # Set data rate and upload to ADC
        self._data_rate[port] = data_rate
        self._reconfigureADC(port)


    ## Set the gain for a whole ADC
    # 
    # @param port Which ADC to configure
    # @param gain The new gain
    def setAnalogGain(self, port: PEPORT_A, gain: ADS1115_Registers.ADS1115_PGA):
        if(port > PEPORT_A.PEPORT_A1 or port < PEPORT_A.PEPORT_AK): return

        # Set gain and upload to ADC
        self._gain[port] = gain
        self._reconfigureADC(port)


    ## Reads from an ADC, convert to input voltage
    # 
    # @param pin Which pin to read
    # @return The resulting value in volt
    def analogReadAsVoltage(self, pin: PEPIN_A) -> float:
        if(not ((pin >= PEPIN_A.PEPIN_AK1 or pin <= PEPIN_A.PEPIN_AK4) or 
            (pin >= PEPIN_A.PEPIN_A10 or pin <= PEPIN_A.PEPIN_A13))): return 0.0 

        port = PEPORT_A.PEPORT_A1 if (pin >= PEPIN_A.PEPIN_A10) else PEPORT_A.PEPORT_AK
        real_pin = pin - PEPIN_A.PEPIN_A10 if (pin >= PEPIN_A.PEPIN_A10) else pin

        # Perform single shot measurement
        # Configure mux in open ended mode
        self._bus.write_i2c_block_data(self._adc_address[port], ADS1115_Registers.ADS1115_REG_POINTER_CONFIG, [
            (ADS1115_Registers.ADS1115_REG_CONFIG_HI_OS_BEGIN | ADS1115_Registers.ADS1115_REG_CONFIG_HI_MUX_AIN_N_GND |
                ((real_pin << ADS1115_Registers.ADS1115_REG_CONFIG_HI_MUX_AIN_P_OFFSET) & ADS1115_Registers.ADS1115_REG_CONFIG_HI_MUX_AIN_P_MASK) |
                self._gain[port] | ADS1115_Registers.ADS1115_REG_CONFIG_HI_MODE_SINGLESHOT),
            (self._data_rate[port] | ADS1115_Registers.ADS1115_REG_CONFIG_LO_COMP_MODE_TRAD |
                ADS1115_Registers.ADS1115_REG_CONFIG_LO_COMP_POL_LOW | ADS1115_Registers.ADS1115_REG_CONFIG_LO_COMP_LAT_NON |
                ADS1115_Registers.ADS1115_REG_CONFIG_LO_COMP_QUE_DISABLE)
        ])
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

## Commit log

2021-06-11 Add design goals
    [power-extender.kicad_pcb, power-extender.sch]
2021-06-13 First version of relays and measurement circuits
    [power-extender.kicad_pcb, power-extender.sch, relay.sch]
2021-06-14 First draft
    [power-extender.sch, relay.sch]
2021-06-14 Firnish schematic first version
    [power-extender.kicad_pcb, power-extender.sch, relay.sch]
2021-06-15 checkpoint commit
    [power-extender.kicad_pcb, power-extender.sch, relay.sch]
2021-06-16 relay layout checkpoint
    [power-extender.kicad_pcb, power-extender.sch, relay-mir.sch]
2021-06-16 traces done
    [power-extender.kicad_pcb, power-extender.sch, relay-mir.sch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]
2021-06-16 first verion of layout done
    [power-extender.kicad_pcb]
2021-06-17 Add bjt pulldown, prepare for export
    [power-extender.kicad_pcb, power-extender.sch, power-extender_bom_rev1.xlsx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]
2021-06-18 rev1 final touchups
    [bom_rev1.xlsx, power-extender.kicad_pcb, power-extender_bom_rev1.xlsx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]
2021-06-18 Submit rev1
    [bom_rev1.xlsx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]
2021-06-18 save file
    [power-extender.kicad_pcb]
2021-06-21 Add rev 1.1 fabrication files
    [T-U4W100177A-3sets-power-extender-bom-rev1--Arya-2021.6.18-ok-r1.1.xlsx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]
2021-07-15 Begin implementing arduino library
2021-07-16 Add arduino library
2021-07-16 Add pdf schematics
2021-07-20 Add raspberry pi python library
2022-05-26 fix cubecell board incompatibilities
    [PowerExtender.py, main.cpp]
